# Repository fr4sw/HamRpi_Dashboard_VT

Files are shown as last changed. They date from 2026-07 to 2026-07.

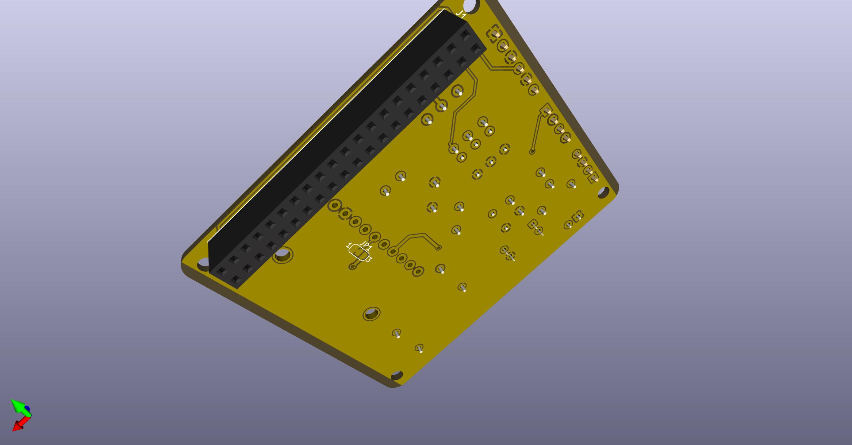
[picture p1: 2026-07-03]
Hardware/HamRpi_Dashboard_VT_3DB.jpg

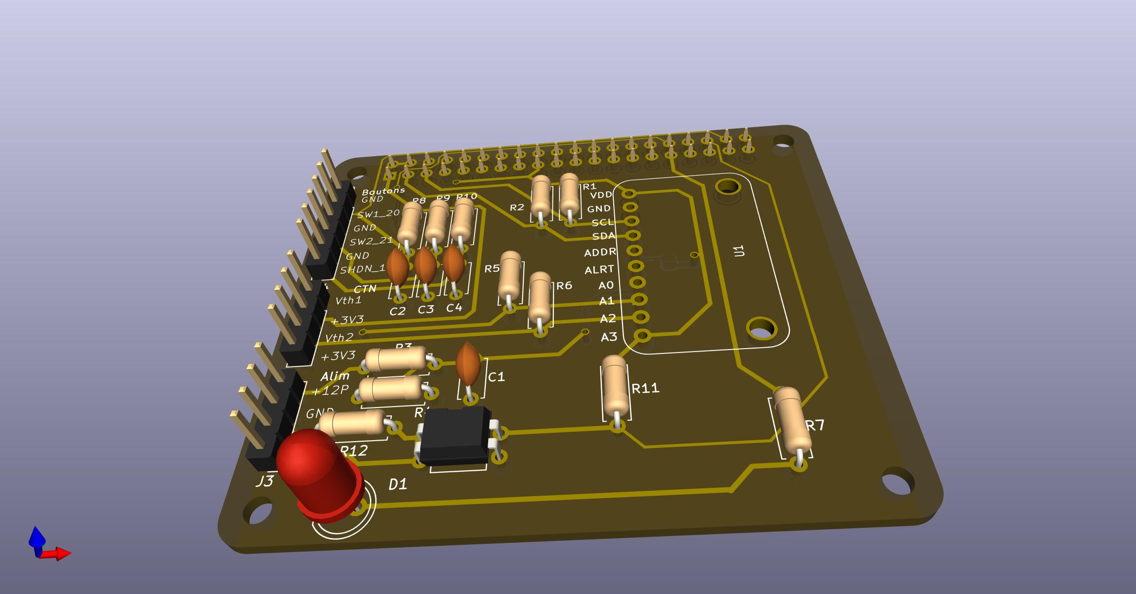
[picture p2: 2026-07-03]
Hardware/HamRpi_Dashboard_VT_3DA.jpg

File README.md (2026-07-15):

Projet de l'Association Réunionaise des Radio Amateurs

Objectif Global : permettre la supervision de l'autonomie des stations automatiques basées sur RaspberryPi

La carte permet :
de remonter au RaspberryPi diverses informations :
- Présence du 5V (GPIO 16) avec isolation galvanique par optocoupleur
- Tension d'alimentation 12V (via ADC) par pont diviseur (à ajuster)
- Tension d'alimentation 3,3V issu du RaspberryPi (via ADC)
- Température par CTN externes (2 canaux) (ajuster les résistances) (via ADC)

les tensions (et températures) sont remontées par un ADS1115 sur le bus I2C (Ad 0x48 par défaut, modifiable par JP1)

de commander le RaspberryPi :
- 3 boutons (GPIO 20, 21, 12)

D'afficher des états :
- une LED (GPIO06)

Le PCB a été lancé en fabrication (JLCPCB) le 2 juillet, fourni à l'ARRA le 15/7/26 -> release 1.0

Date : 15 juillet 2026

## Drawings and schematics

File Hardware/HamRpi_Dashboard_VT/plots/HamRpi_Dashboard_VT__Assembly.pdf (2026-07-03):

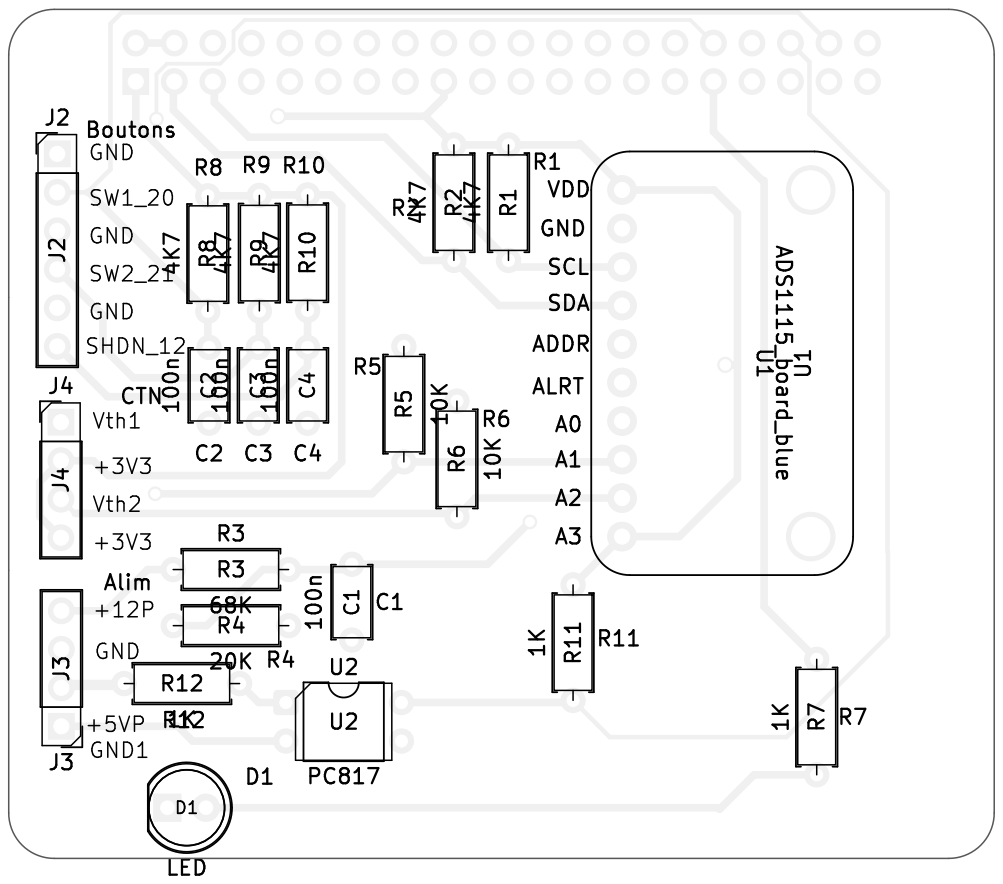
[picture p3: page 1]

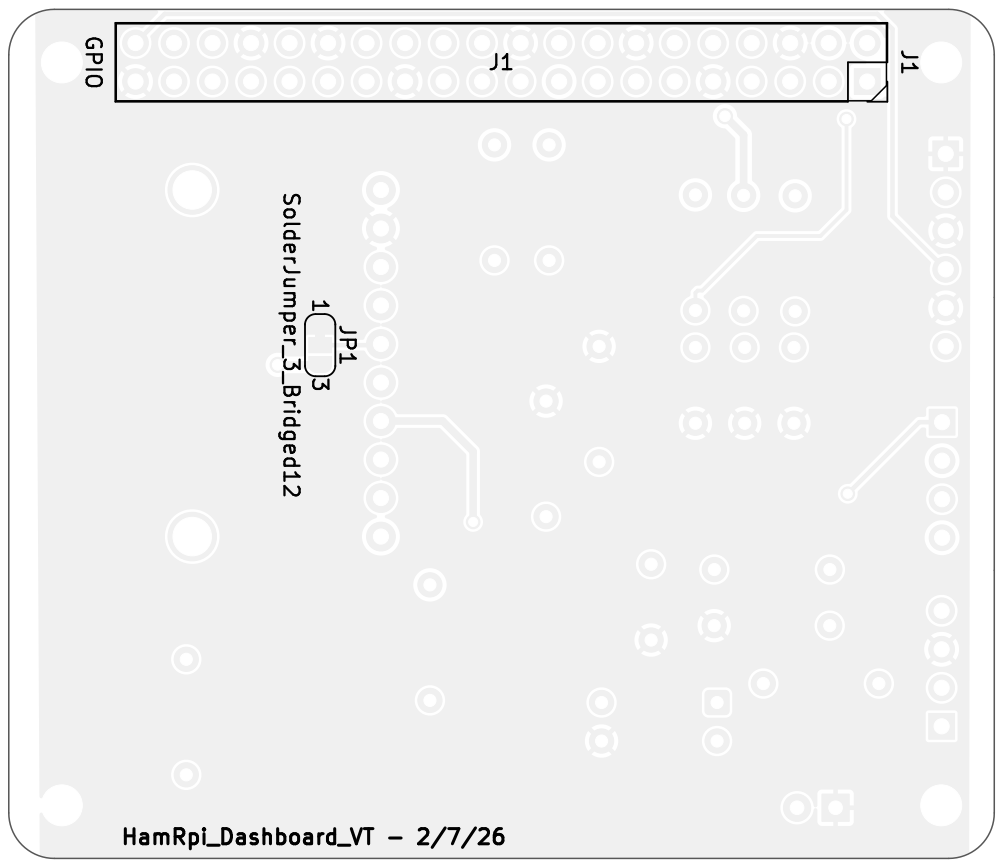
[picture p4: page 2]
HamRpi_Dashboard_VT - 2/7/26; D Date: 2026-06-27 KiCad; E.D.A. 9.0.9 Size: A4; Rev:; Id: /1 Title: File: HamRpi_Dashboard_VT.kicad_pcb Sheet: Black; And; White; BOT Auteur :; MOA :; Board2Pdf:; Black; BOT -; Page 2/8 GPIO; J1 SolderJumper_3_Bridged12

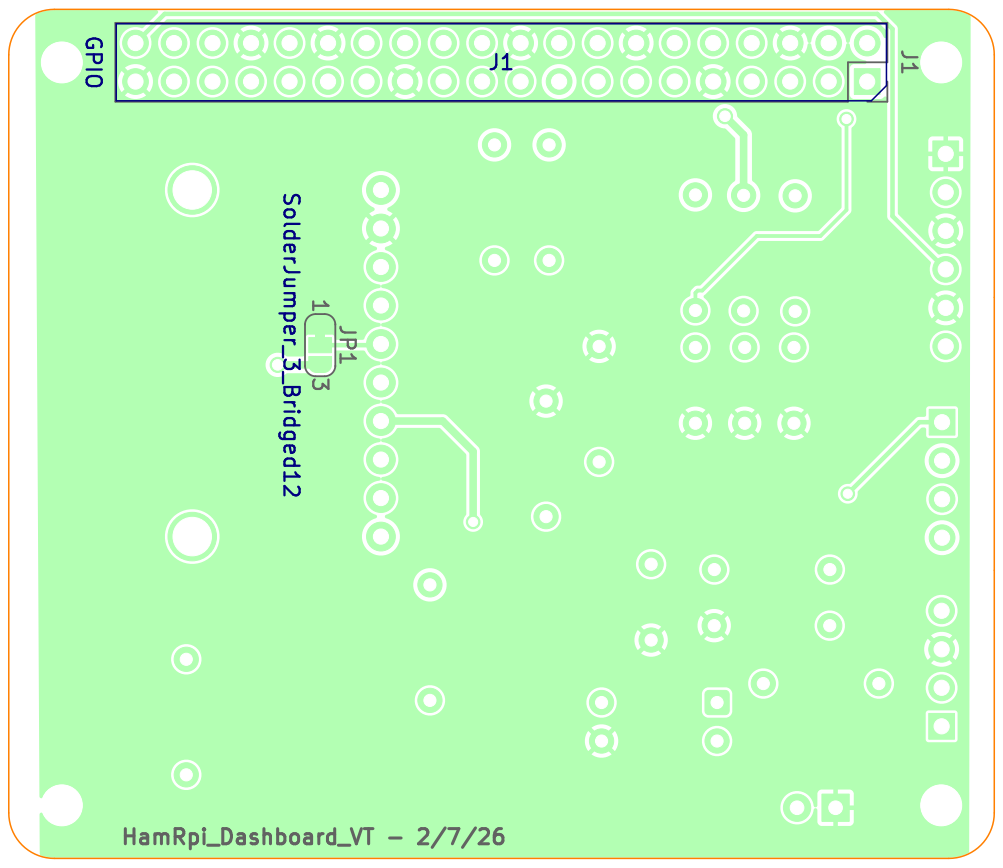
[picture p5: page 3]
HamRpi_Dashboard_VT - 2/7/26; D Date: 2026-06-27 KiCad; E.D.A. 9.0.9 Size: A4; Rev:; Id: /1 Title: File: HamRpi_Dashboard_VT.kicad_pcb Sheet: Colored; BOT Auteur :; MOA :; Board2Pdf:; Colored; BOT -; Page 3/8 GPIO; J1 SolderJumper_3_Bridged12

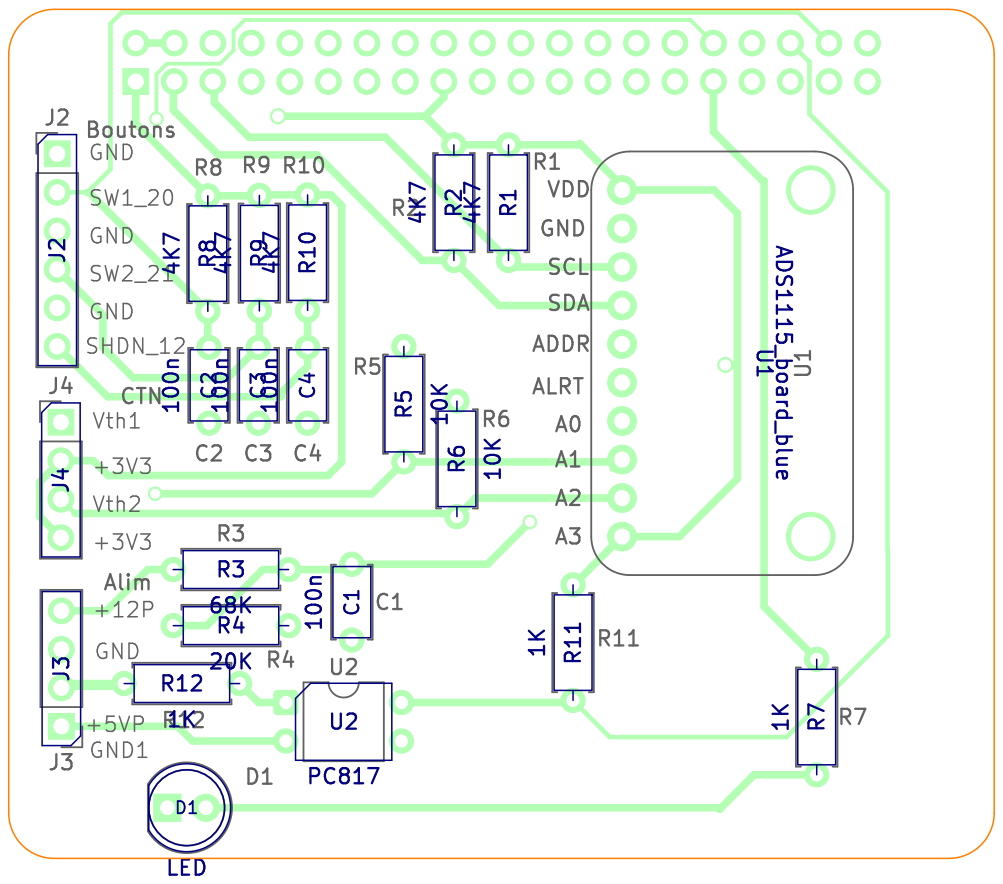
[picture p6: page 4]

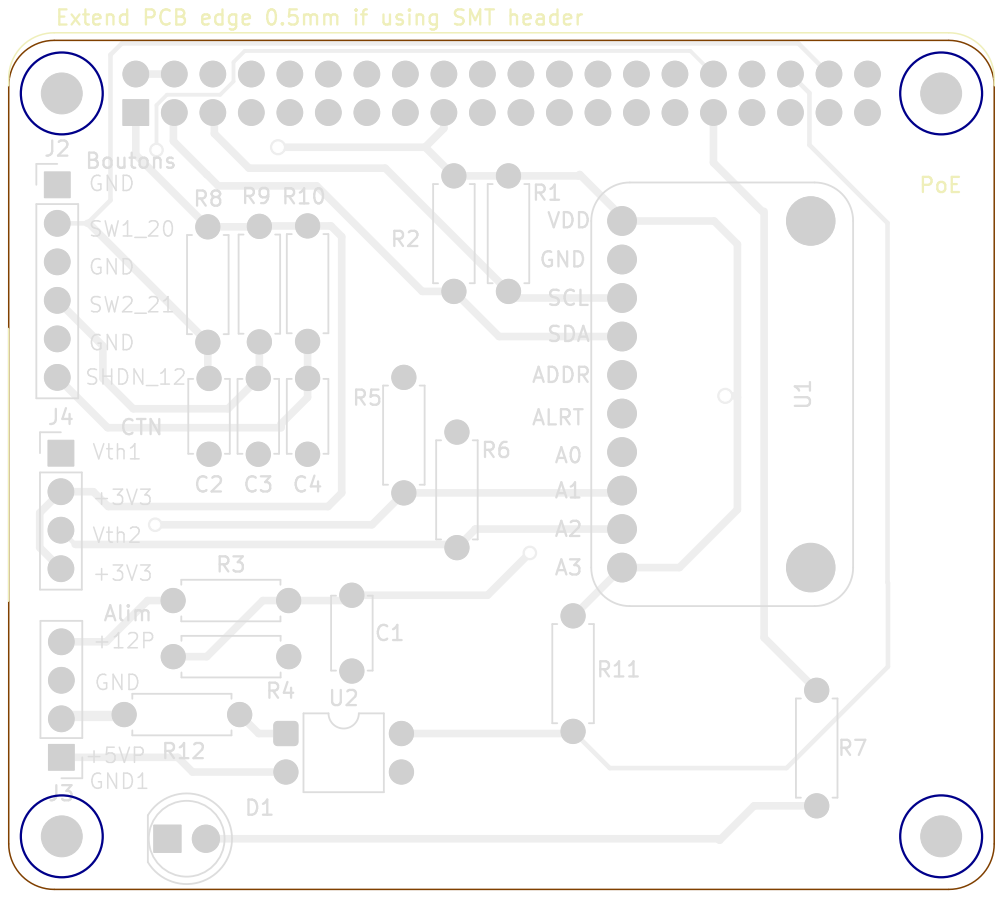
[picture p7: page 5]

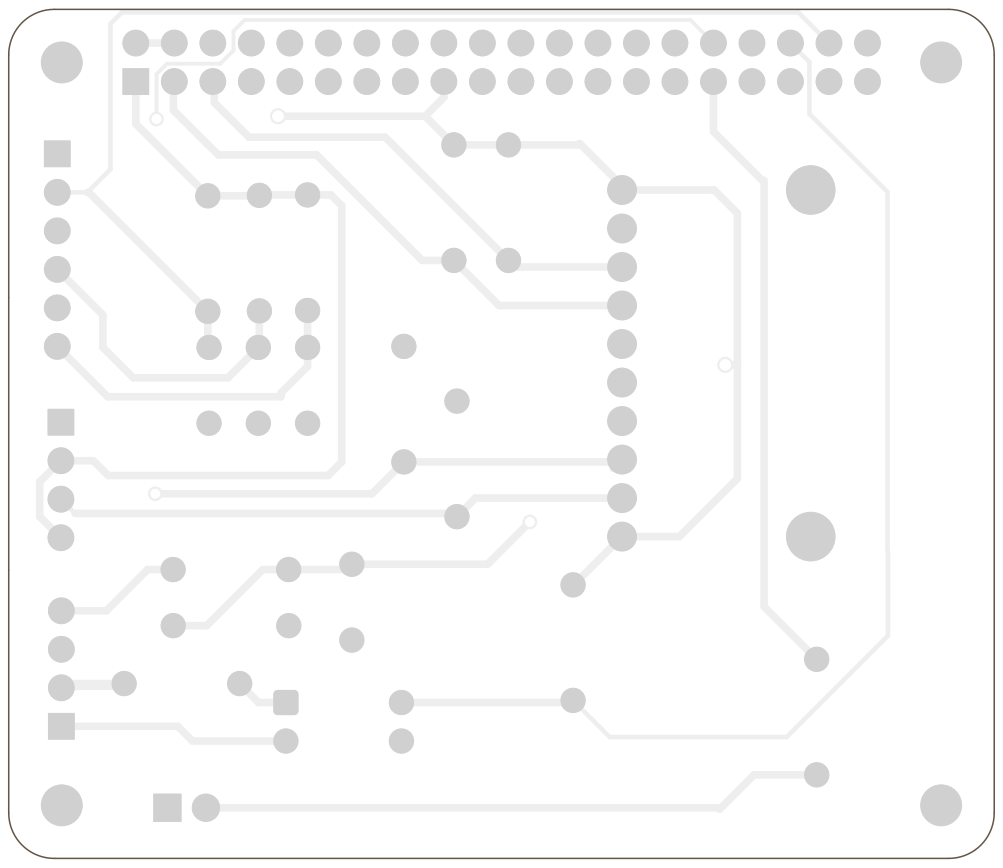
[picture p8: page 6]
D Date: 2026-06-27 KiCad; E.D.A. 9.0.9 Size: A4; Rev:; Id: /1 Title: File: HamRpi_Dashboard_VT.kicad_pcb Sheet: Light Colors; PCB; Paste; TOP; Auteur :; MOA :; Board2Pdf:; Light Colors; TOP -; Page 6/8

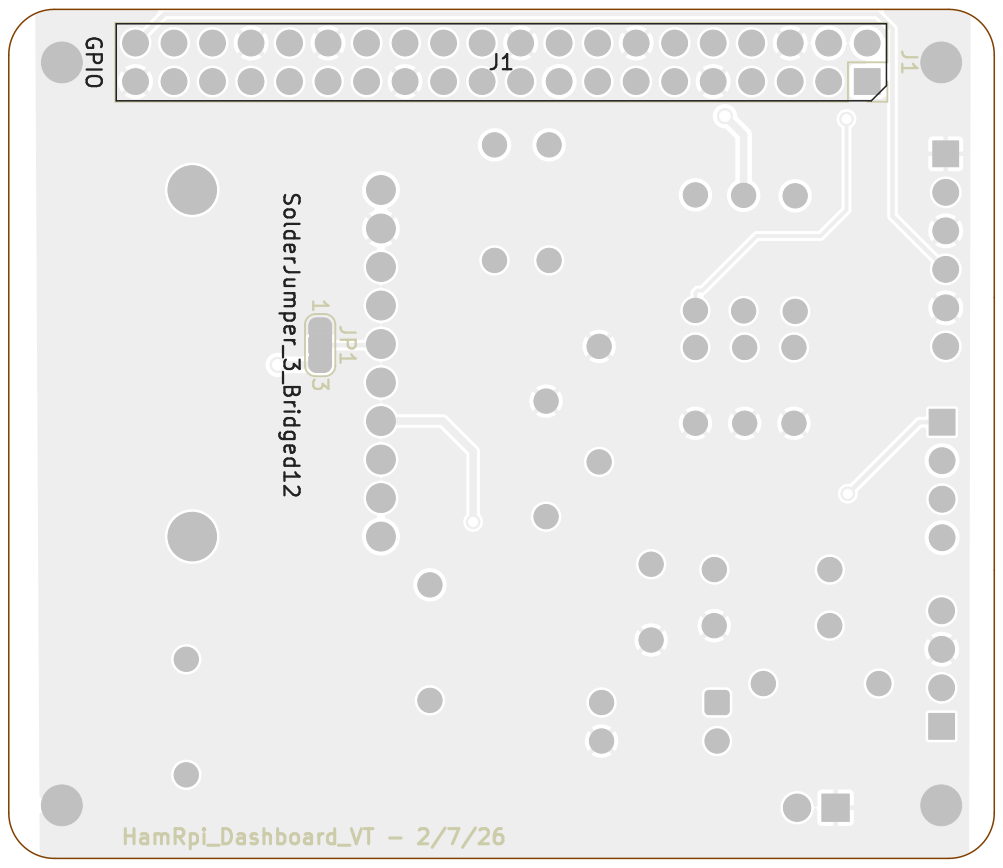
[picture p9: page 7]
HamRpi_Dashboard_VT - 2/7/26; 3 1 GPIOJ1 SolderJumper_3_Bridged12; D Date: 2026-06-27 KiCad; E.D.A. 9.0.9 Size: A4; Rev:; Id: /1 Title: File: HamRpi_Dashboard_VT.kicad_pcb Sheet: Light Colors; Placement; BOT Auteur :; MOA :; Board2Pdf:; Light Colors; BOT -; Page 7/8

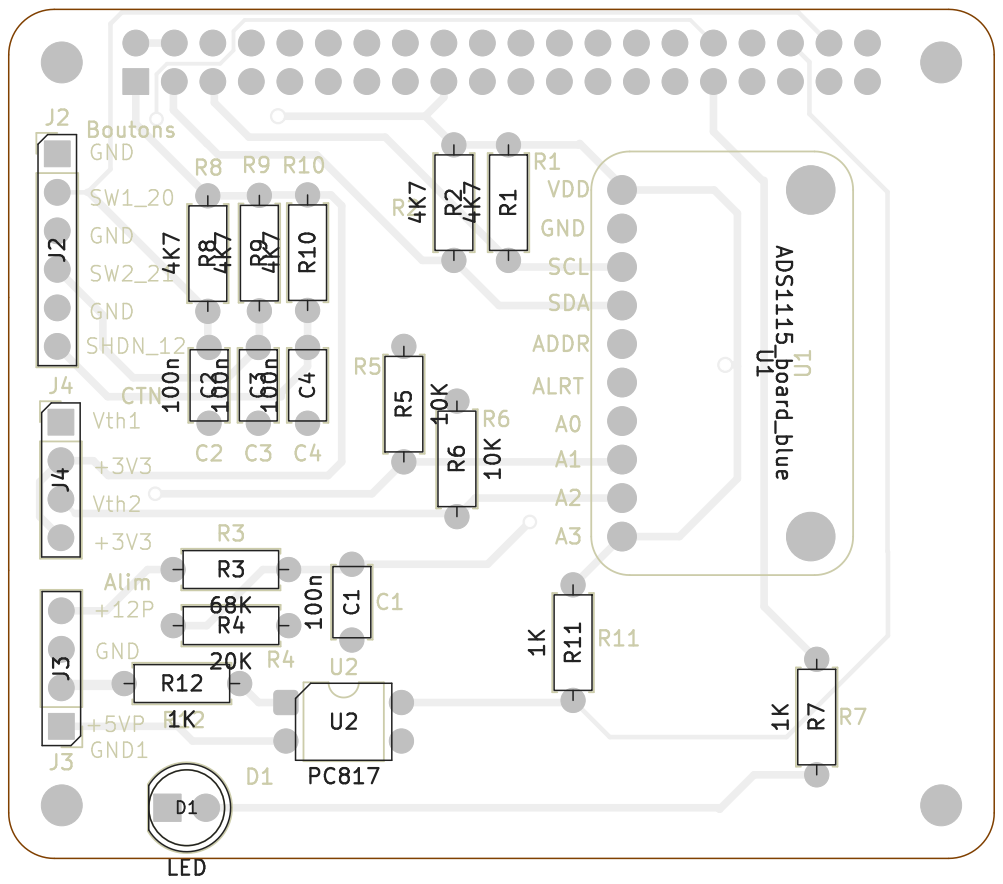
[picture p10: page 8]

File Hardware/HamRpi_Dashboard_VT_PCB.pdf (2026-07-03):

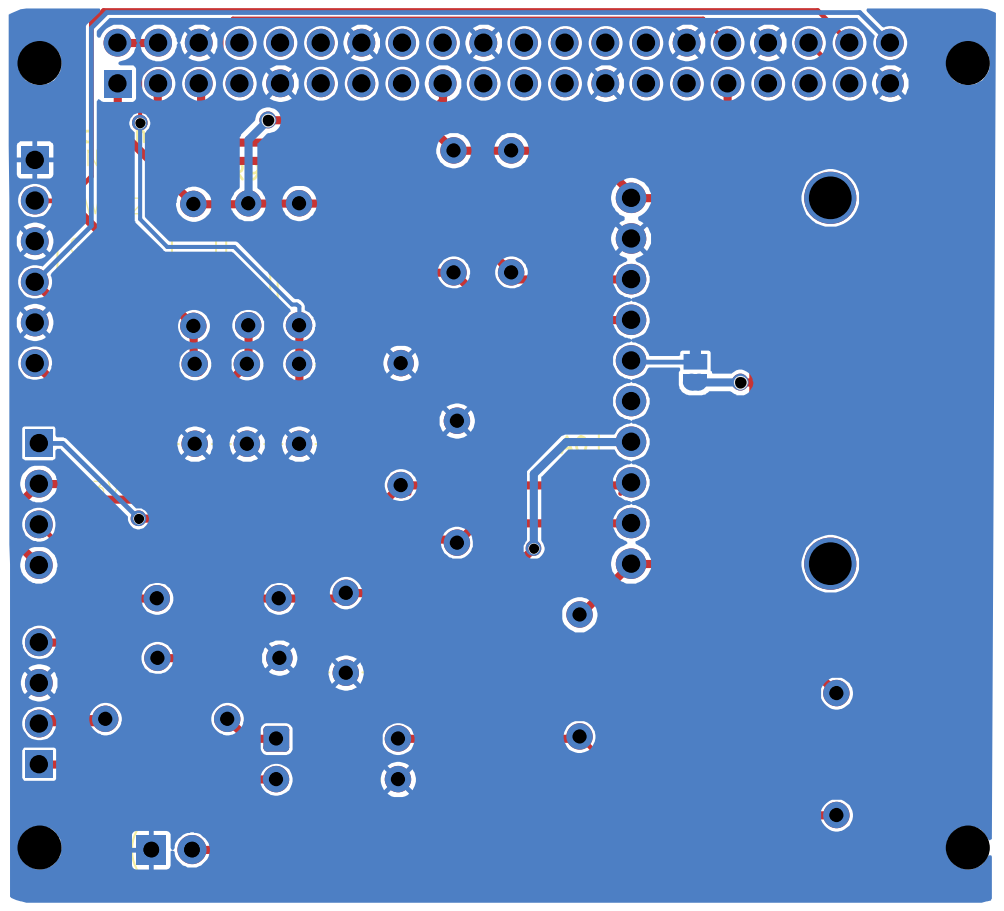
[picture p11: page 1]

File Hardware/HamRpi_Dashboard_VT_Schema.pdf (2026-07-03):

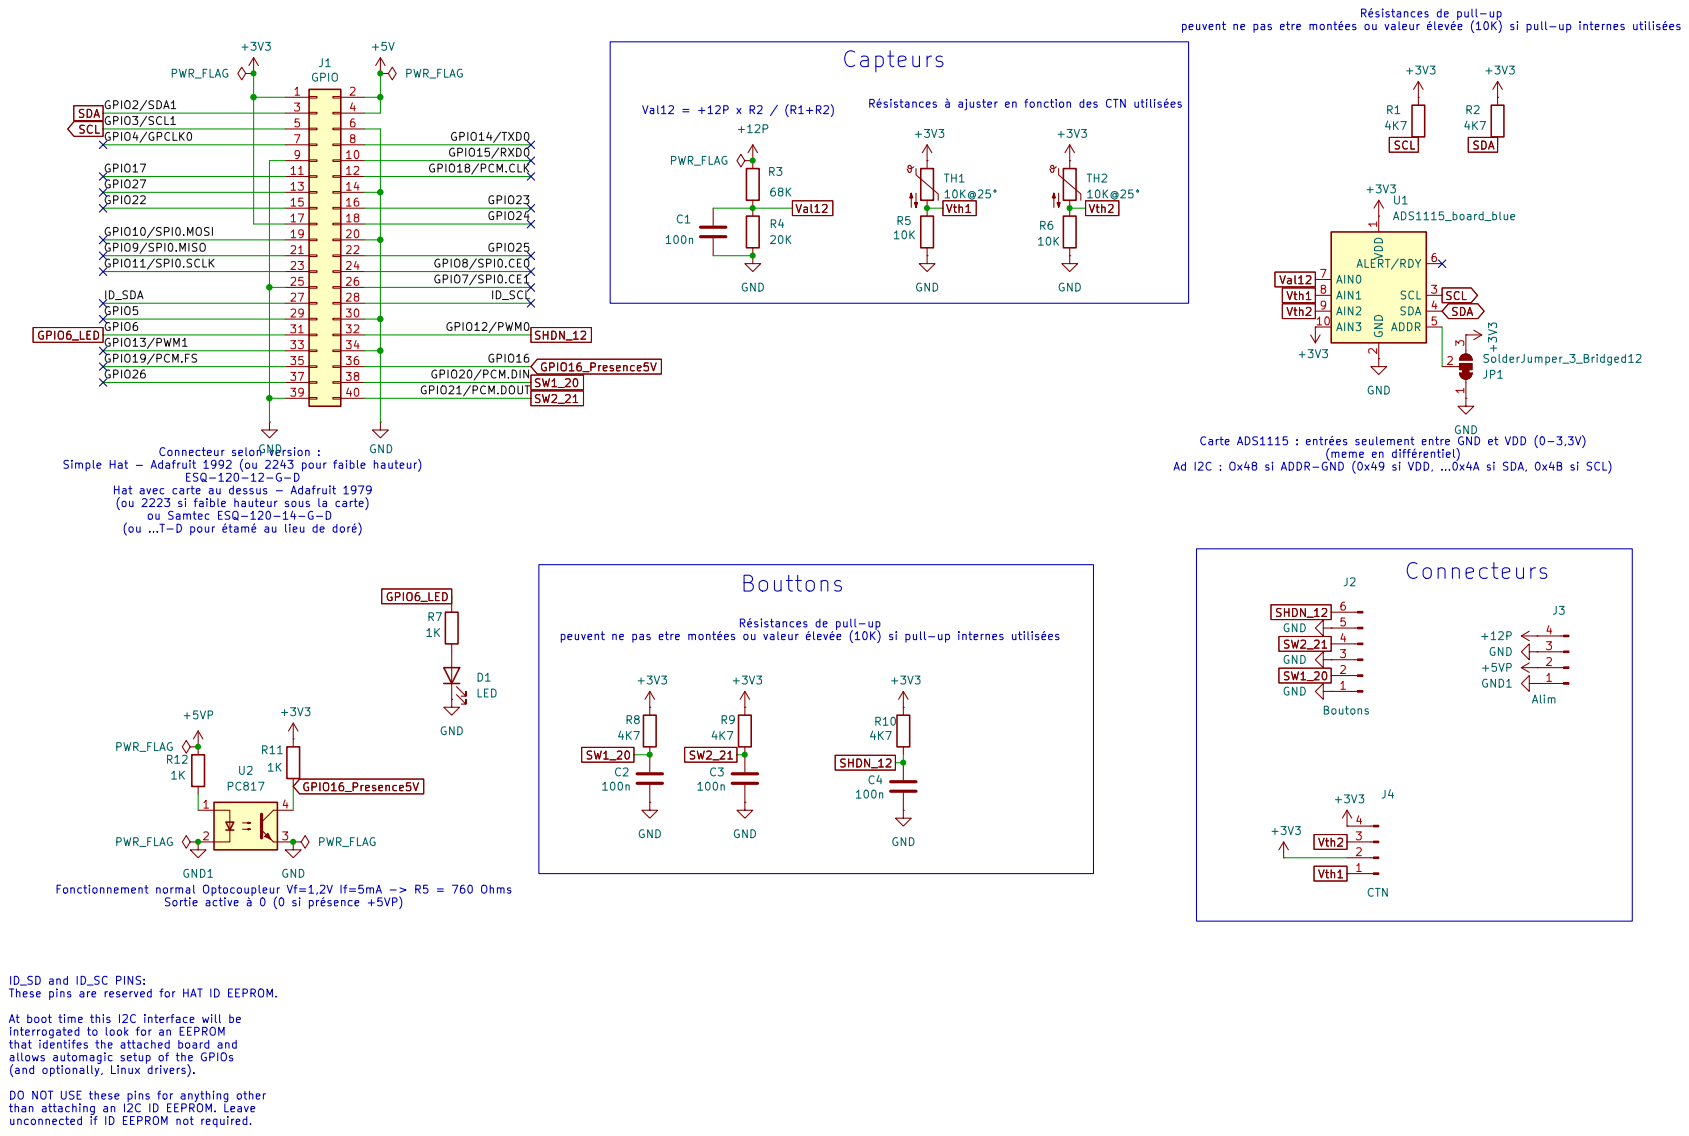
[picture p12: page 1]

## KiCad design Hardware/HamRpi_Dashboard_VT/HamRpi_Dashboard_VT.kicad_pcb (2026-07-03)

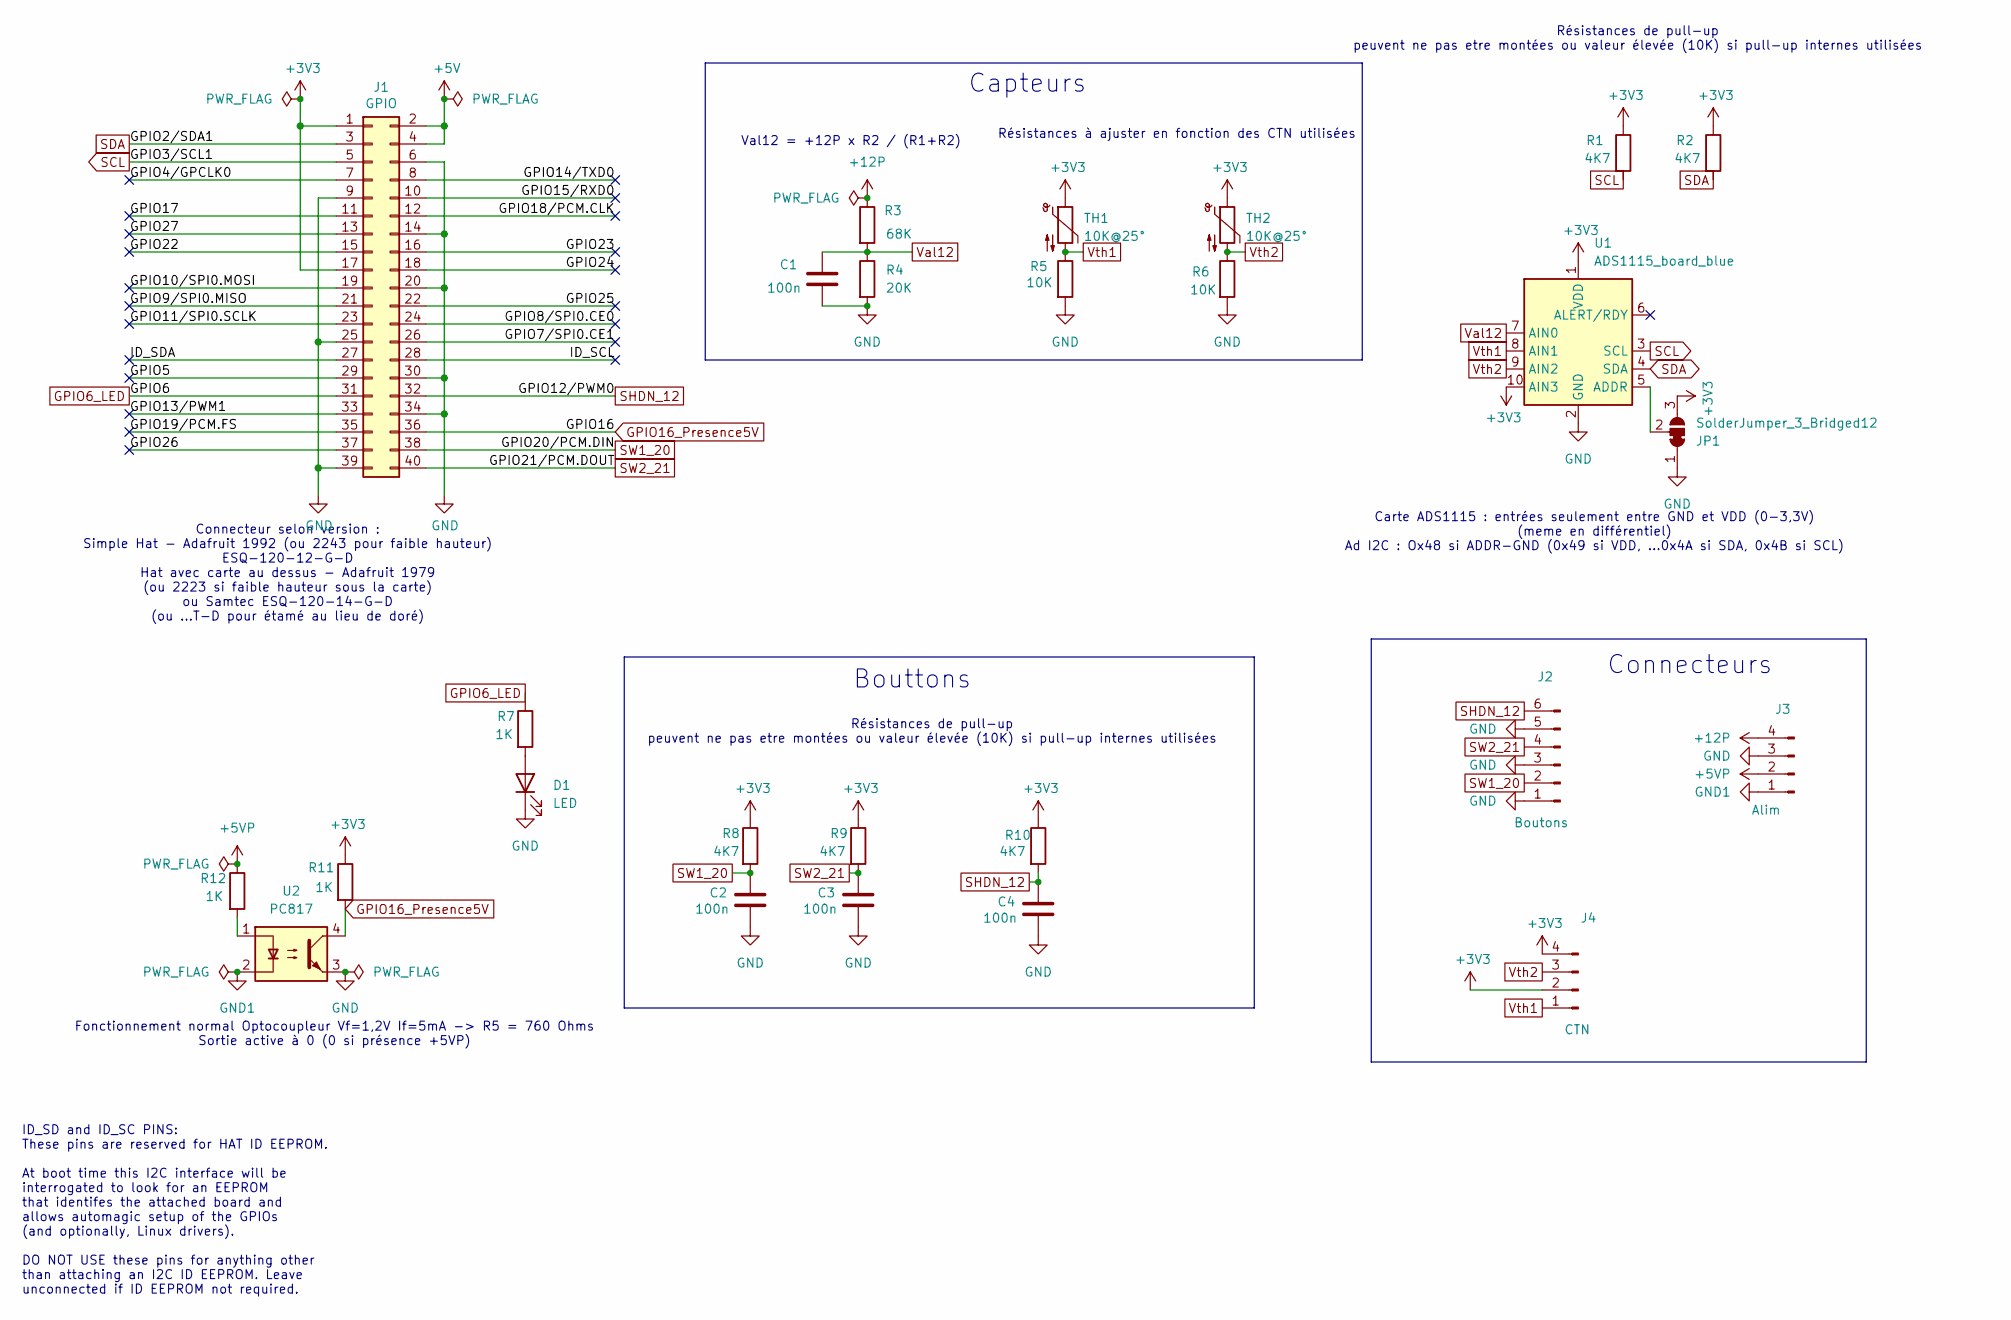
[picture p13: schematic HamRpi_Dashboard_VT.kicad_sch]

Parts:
C1, C2, C3, C4: 100n; C_Disc_D4.7mm_W2.5mm_P5.00mm; MPN FG28X7R1H104KNT06
D1: LED; LED_D5.0mm
J1: GPIO; PinSocket_2x20_P2.54mm_Vertical; MPN 1979
J2: Boutons; PinHeader_1x06_P2.54mm_Vertical_NetName
J3: Alim; PinHeader_1x04_P2.54mm_Vertical_NetName
J4: CTN; PinHeader_1x04_P2.54mm_Vertical_NetName
JP1: SolderJumper_3_Bridged12; SolderJumper-3_P1.3mm_Bridged12_RoundedPad1.0x1.5mm_NumberL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
R1, R2, R8, R9, R10: 4K7; R_Axial_DIN0207_L6.3mm_D2.5mm_P7.62mm_Horizontal; MPN MFR-25FRF52-4K7
R3: 68K; R_Axial_DIN0207_L6.3mm_D2.5mm_P7.62mm_Horizontal; MPN MFR-25FRF52-68K
R4: 20K; R_Axial_DIN0207_L6.3mm_D2.5mm_P7.62mm_Horizontal; MPN MFR-25FRF52-20K
R5, R6: 10K; R_Axial_DIN0207_L6.3mm_D2.5mm_P7.62mm_Horizontal; MPN MFR-25FRF52-10K
R7, R11, R12: 1K; R_Axial_DIN0207_L6.3mm_D2.5mm_P7.62mm_Horizontal; MPN MFR-25FRF52-1K
TH1, TH2: 10K@25°; R_Axial_DIN0204_L3.6mm_D1.6mm_P5.08mm_Horizontal; MPN NTCLE100E3103HT1
U1: ADS1115_board_blue; Adafruit_ADS1115_modifie; MPN 26203
U2: PC817; DIP-4_W7.62mm; MPN PC817X1NSZ0F

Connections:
+3V3: J1.1, J1.17, J4.2, J4.4, JP1.3 (B), R1.1, R2.1, R8.1, R9.1, R10.1, R11.1, TH1.1, TH2.1, U1.1 (VDD), U1.10 (AIN3)
+5V: J1.2, J1.4
+5VP: J3.2, R12.1
+12P: J3.4, R3.1
/GPIO4/GPCLK0: J1.7
/GPIO5: J1.29
/GPIO7/SPI0.CE1: J1.26
/GPIO8/SPI0.CE0: J1.24
/GPIO9/SPI0.MISO: J1.21
/GPIO10/SPI0.MOSI: J1.19
/GPIO11/SPI0.SCLK: J1.23
/GPIO13/PWM1: J1.33
/GPIO14/TXD0: J1.8
/GPIO15/RXD0: J1.10
/GPIO17: J1.11
/GPIO18/PCM.CLK: J1.12
/GPIO19/PCM.FS: J1.35
/GPIO22: J1.15
/GPIO23: J1.16
/GPIO24: J1.18
/GPIO25: J1.22
/GPIO26: J1.37
/GPIO27: J1.13
/ID_SCL: J1.28
/ID_SDA: J1.27
GND: C1.2, C2.2, C3.2, C4.2, D1.1 (K), J1.6, J1.9, J1.14, J1.20, J1.25, J1.30, J1.34, J1.39, J2.1, J2.3, J2.5, J3.3, JP1.1 (A), R4.2, R5.2, R6.2, U1.2 (GND), U2.3
GND1: J3.1, U2.2
GPIO6_LED: J1.31, R7.1
GPIO16_Presence5V: J1.36, R11.2, U2.4
unnamed: D1.2 (A), R7.2
unnamed: JP1.2 (C), U1.5 (ADDR)
unnamed: R12.2, U2.1
SCL: J1.5, R1.2, U1.3 (SCL)
SDA: J1.3, R2.2, U1.4 (SDA)
SHDN_12: C4.1, J1.32, J2.6, R10.2
SW1_20: C2.1, J1.38, J2.2, R8.2
SW2_21: C3.1, J1.40, J2.4, R9.2
Val12: C1.1, R3.2, R4.1, U1.7 (AIN0)
Vth1: J4.1, R5.1, TH1.2, U1.8 (AIN1)
Vth2: J4.3, R6.1, TH2.2, U1.9 (AIN2)

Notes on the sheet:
Résistances de pull-up peuvent ne pas etre montées ou valeur élevée (10K) si pull-up internes utilisées
Val12 = +12P x R2 / (R1+R2)
Connecteurs
Capteurs
Résistances à ajuster en fonction des CTN utilisées
Connecteur selon version : Simple Hat - Adafruit 1992 (ou 2243 pour faible hauteur) ESQ-120-12-G-D Hat avec carte au dessus - Adafruit 1979 (ou 2223 si faible hauteur sous la carte) ou Samtec ESQ-120-14-G-D (ou ...T-D pour étamé au lieu de doré)
ID_SD and ID_SC PINS: These pins are reserved for HAT ID EEPROM. At boot time this I2C interface will be interrogated to look for an EEPROM that identifes the attached board and allows automagic setup of the GPIOs (and optionally, Linux drivers). DO NOT USE these pins for anything other than attach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
Carte ADS1115 : entrées seulement entre GND et VDD (0-3,3V) (meme en différentiel) Ad I2C : Ox48 si ADDR-GND (0x49 si VDD, ...0x4A si SDA, 0x4B si SCL)
Bouttons
Fonctionnement normal Optocoupleur Vf=1,2V If=5mA -> R5 = 760 Ohms Sortie active à 0 (0 si présence +5VP)

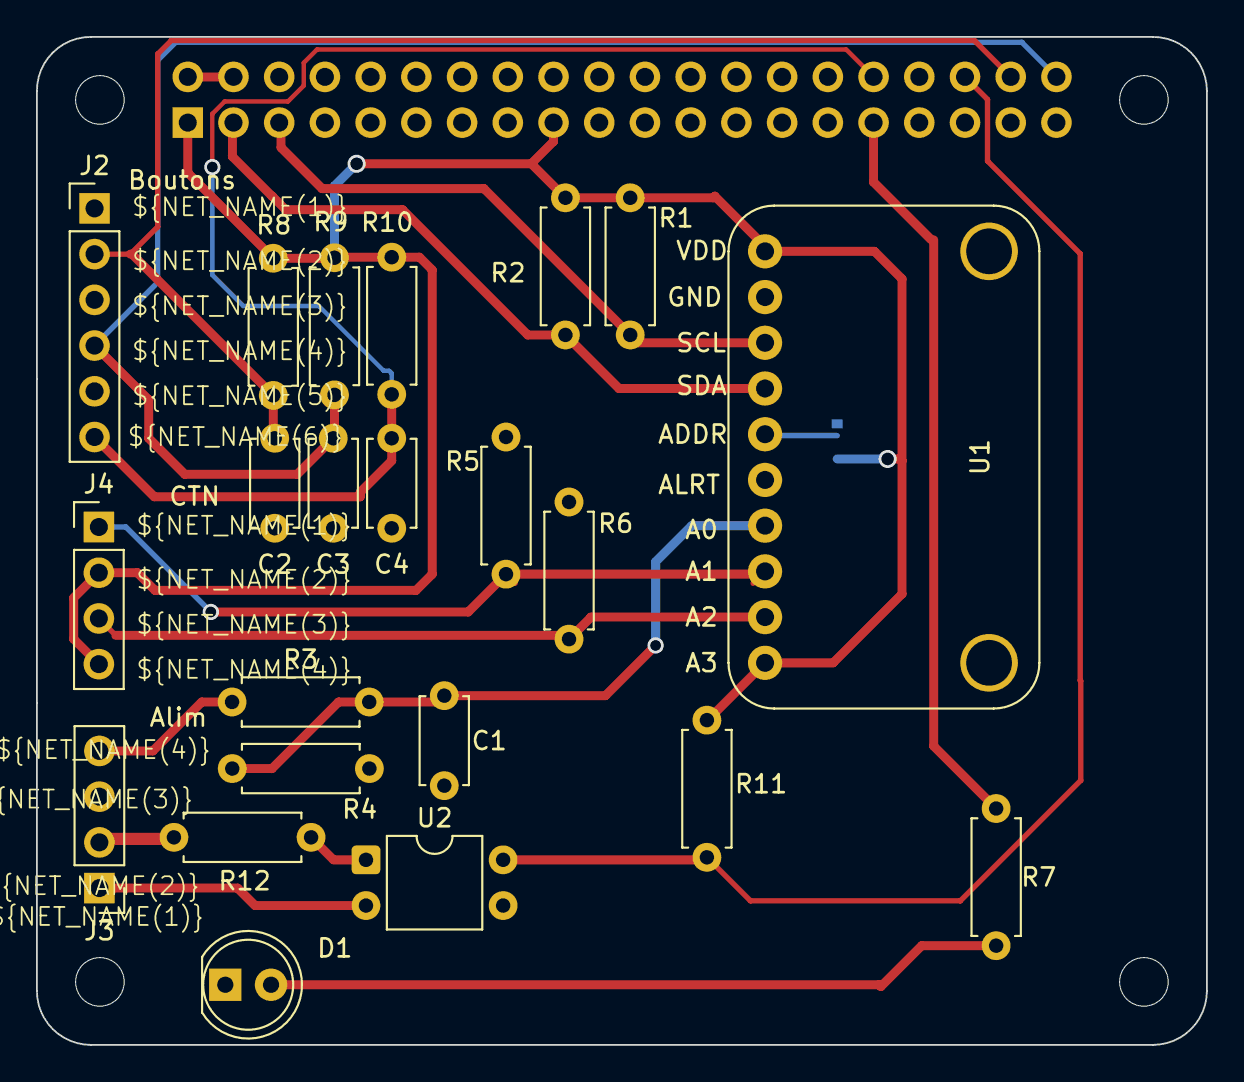
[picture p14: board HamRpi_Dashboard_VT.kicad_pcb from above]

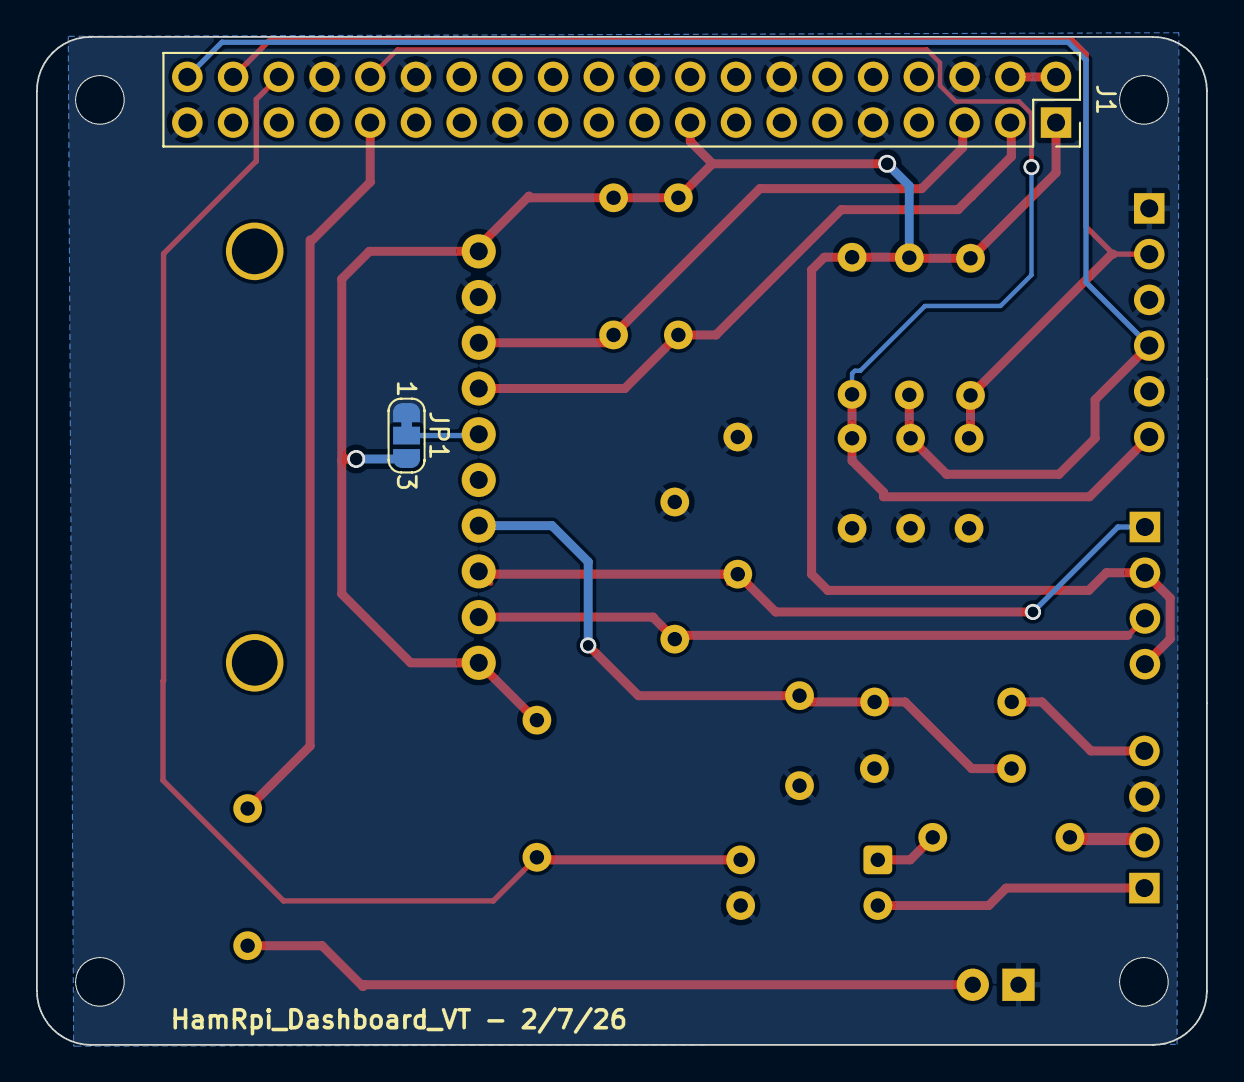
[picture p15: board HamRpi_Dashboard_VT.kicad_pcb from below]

Board: 2 copper layers, 65.0 x 56.0 mm, 28 parts (2 on the bottom side), 19 nets.

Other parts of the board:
MH1, MH2, MH3, MH4: MountingHole_2.7mm_M2.5
